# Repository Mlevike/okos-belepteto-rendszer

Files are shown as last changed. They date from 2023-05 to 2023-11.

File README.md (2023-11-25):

# okos-belepteto-rendszer
Okos, internetre kötött beléptető rendszer Raspberry Pi és Arduino alapokon.

# A rendszer leírása
A projekt céja egy hálózaton keresztül elérhető beléptető rendszer megvalósítása, amely engedélyezi a regisztrált felhasználók számára a belépést RFID kártya segítségével. A biztonság növelése érdekében az RFID kártya leovasását követően a felhasználóknak meg kell adni a saját 4 karakter hosszú PIN kódját és/vagy ujjlenyomat segítségével hitelesíteniük kell magukat. A sikeres belépést LED-ekkel, illetve egy 16x2-es karakteres LCD kijelzővel szemléltetjük. 

# Funkciók

- Az RFID jogosultságokat, illetve a felhasználók más releváns adatait egy adatbázisban tároljuk.
- A sikeres belépést az LCD megjelenő felirattal és hangjelzéssel jelezzük.
- Sikertelen belépésről az LCD tájékoztat minket a következő felirattal.
- A sikeres, illetve a sikertelen kilépési kísérletről egy LED, illetve hangjelzés segítségével tájékoztat a rendszer.

# A rendszer tervezett felépítése

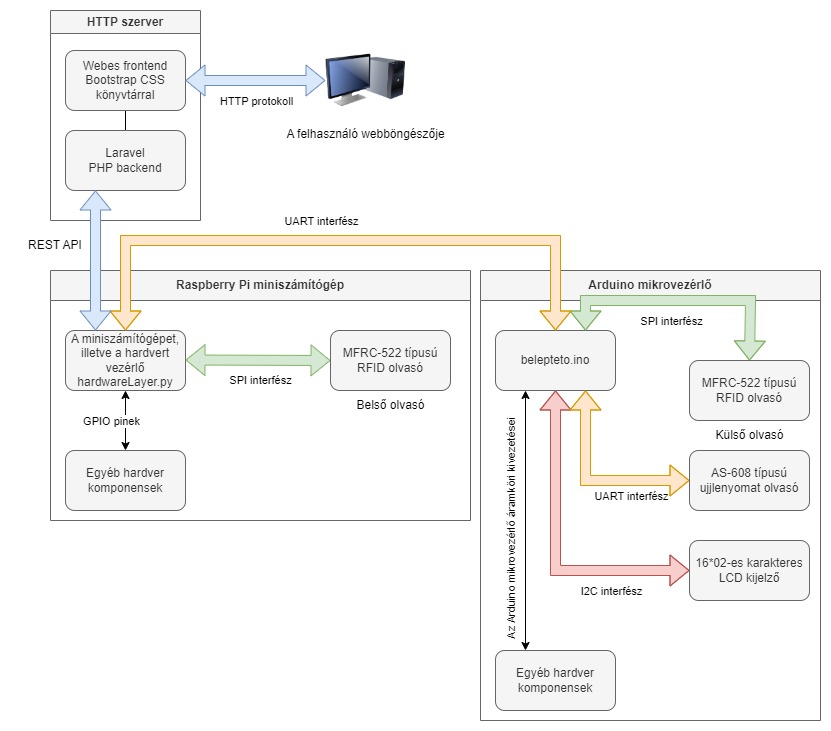
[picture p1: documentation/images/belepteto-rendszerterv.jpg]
Belepteto rendszerterv


# Felhasznált Hardware elemek
- 1 db Raspberry pi 1b rev.2
- 1 db SY-12W-K típusú relé
- 1 db 16x2-es karakteres LCD kijelzővel
- 1 db 4x4-es gomb mátrix
- 2 db RFID olvasó (MFRC-522)
- 1 db Arduino Nano
- 1 db 3,3-5V szintillesztő
- 1 db TM1650 típusú billenytűzet vezérlő IC
- 1 db AS-608 típusú ujjlenyomat olvasó
- 1 db RGB LED
- 2 db Csipogó hangszóró
- Egyéb kisebb alkatrészek

# A rendszer hardveres felépítése
A rendszer két egymástól jól elkülöníthető, ugyanakkor összekapcsolt hardveres részből áll, melyek a következők:

- Az Arduino mikrovezérlőre épülő, melynek felafata a felhasználók beengedéséért felelős külső RFID olvasó, illetve a hozzá tartozó LCD kijelző, ujjlenyomat olvasó, és számbillentyűzet vezérlése.
- A Rasperry Pi, illetve a hozzákapcsolt hardvare elemek, melynek feladata a teljes rendszert vezérlő Python alapú program futtatása, illetve a belső, a felhasználók kiengedéséért felelős RFID kártyaolvasó működtetése.

A kettő rendszer UART soros interfésszel kommunikál egymással, amely megvalósításához szükséges egy 3,3V-5V szintillesztő áramkör.

A két eszköz összekötéséért felelős kábel bekötése:

| A lábel színe és vastagsága | Funkciója | Bekötése az Arduino mikrovezérlőn | Bekötése a Raspberry Pi miniszámítógépen | Megjegyzés |
| --- | --- | --- | --- | --- |
| Vörös / Vastag | 5V táp | VIN (30) | 5V | |
| Fekete / Vastag | Közös föld | GND | GND | |
| Vörös / Vékony | NINCS BEKÖTVE | - | - | |
| Fehér / Vékony | NINCS BEKÖTVE | - | - | |
| Zöld / Vékony | Bejövő UART adatforgalom | TX (1) | RxD / GPIO 16 (10) | A Raspberry Pi felől nézve, 3,3-5V szintillesztőn keresztül a Rasperry Pi védelme érdekében. |
| Sárga / Vékony | Kimenő UART adatforgalom | RX (2) | TxD / GPIO 15 (8) | A Raspberry Pi felől nézve, 3,3-5V szintillesztőn keresztül a Rasperry Pi védelme érdekében. |

## Az Arduino alapú külső olvasó

### Az külső olvasó rövid leírása

A külső olvasó egy Arduino mikrokontroller által vezérelt panel, amelyre csatlakozik a 1602-es LCD kijelző, a kódbillentyűzet, a kártyaolvasó, illetve egy kis hangszóró, amely segítségével a felhasználónak visszajelzést adhatunk a kártya beolvasása során.
A kommunikáció a központi egység és a külső olvasó között soros interfészen valósul meg, az Ardunio, illetve a Raspberry Pi megfelelő lábainak felhasználásával, illetve egy szintillesztő modul közbeikatatásával. A szintillesztő modulra azért van szükség, mert az Arduino a kommunikáció során 5V-os jelszintet használ, míg a Raspberry Pi 3,3V-osat, ezért ha két eszközt közvetlenül csatlakozatnánk, akkor Rasberry Pi károsodna.

### A külső olvasót tartalmazó PCB kivezetései (táblázat)

| Csatlakozás megnevezése | A panel/mikrovezérlő kivezetése | A panelhez csatlakozó modul kivezetése | Megjegyzés |
| --- | --- | --- | --- |
| LCD A kijelző adat kábelei | A4 (23) | SDA | |
| | A5 (24) | SCL | |
| LCD kijelző táp kábelei | 5V | VCC | |
| | GND | GND | |
| MFRC-522 RFID olvasó adat kábelei | D10 (13) | SDA | |
| | D11 (14) | MOSI | |
| | D12 (15) | MISO | |
| | D13 (16) | SCK | |
| MFRC-522 RFID olvasó táp kábelei | 3,3V | 3,3V | |
| | GND | GND | |
| AS-608 ujjlenyomat olvasó adat kábelei | D2 (5) | TX | |
| | D3 (6) | RX | |
| AS-608 ujjlenyomat olvasó táp kábelei  | 3,3V | VCC | |
| | GND | GND | |

### Az olvasó felépítése (Csatlakozók nélkül)

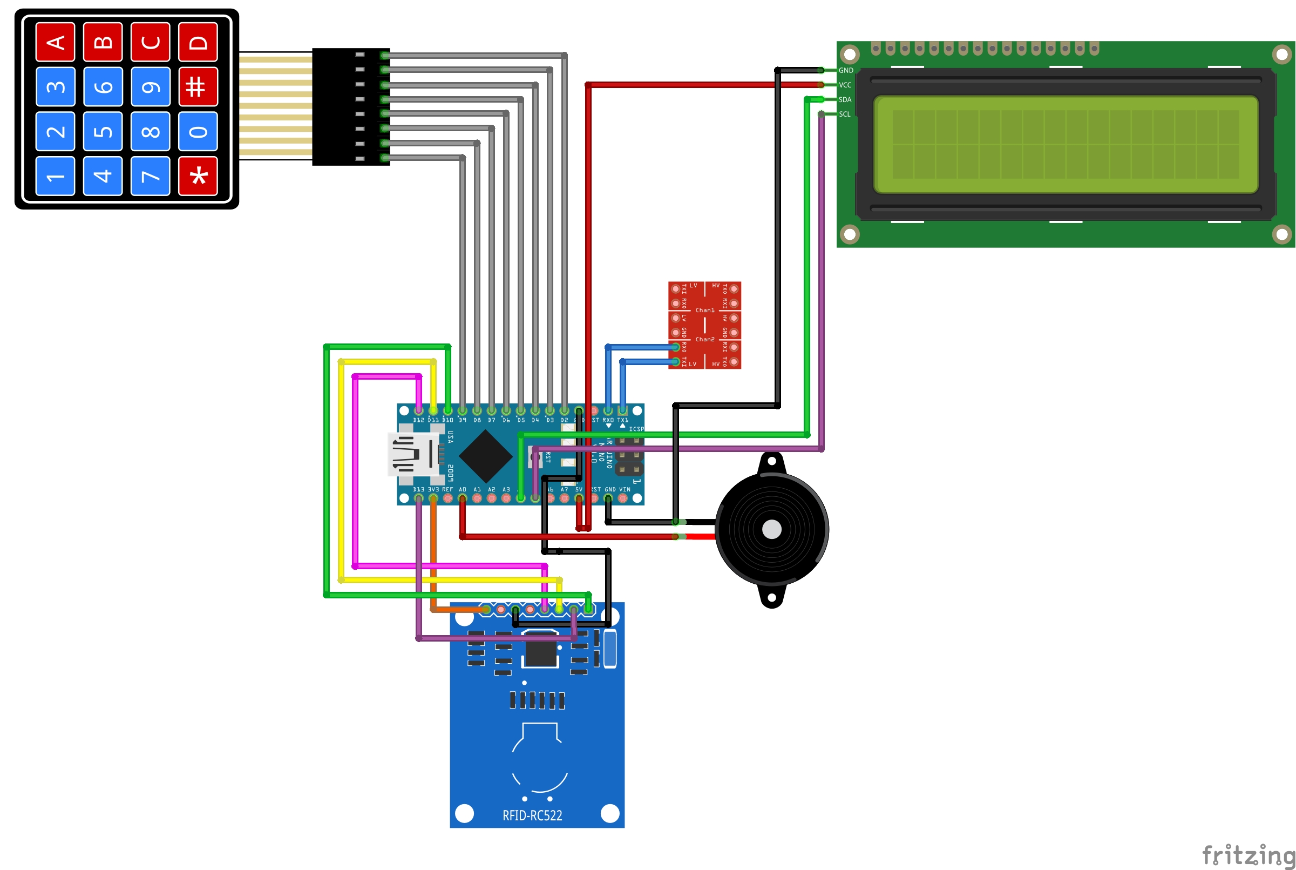
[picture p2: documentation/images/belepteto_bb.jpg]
Beléptető külső olvasó felépítése


### Az olvasó kapcsolási rajza (Csatlakozók nélkül)

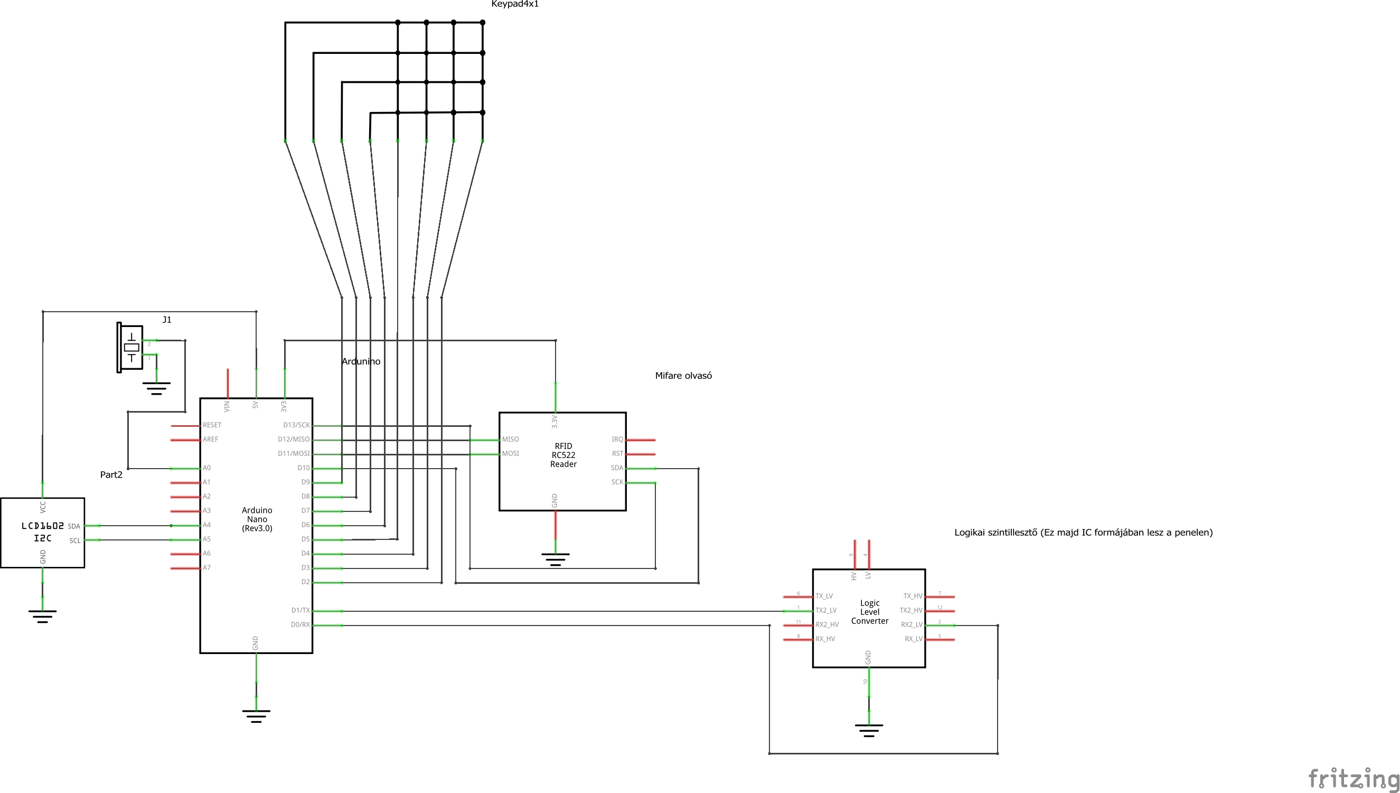
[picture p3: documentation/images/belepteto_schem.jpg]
Beléptető külső olvasó kapcsolási rajza


### Az olvasó nyomtatott áramköri lap terve

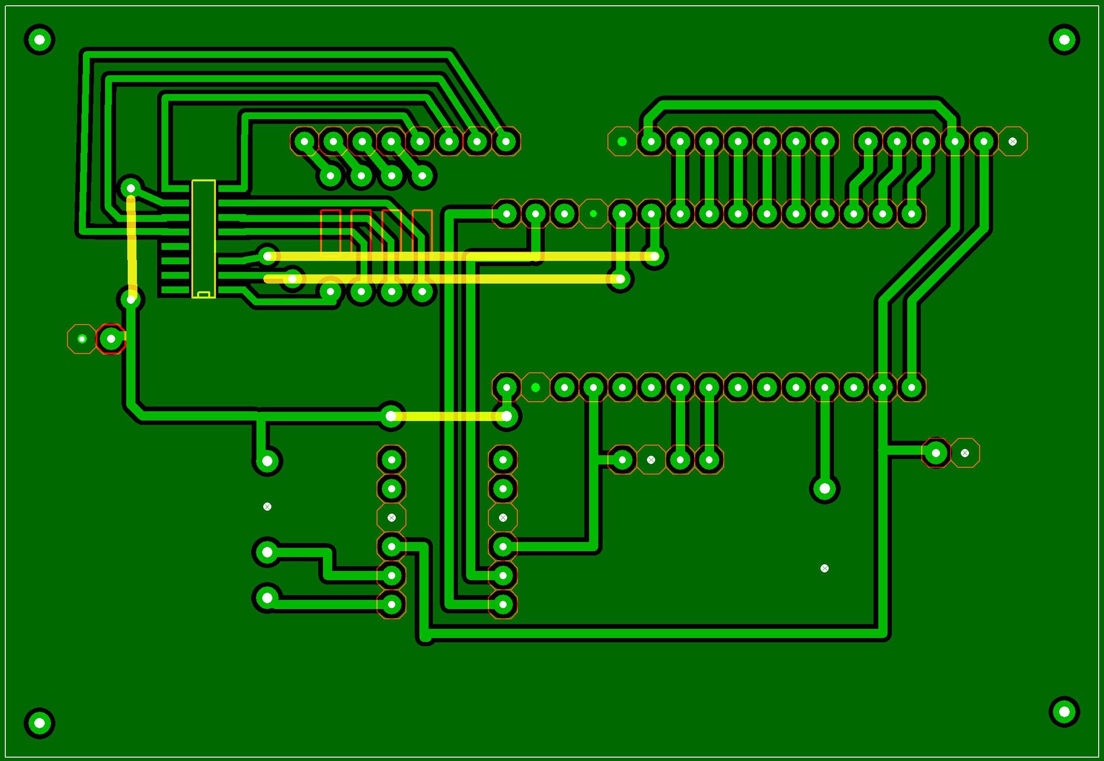
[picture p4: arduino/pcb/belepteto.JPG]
Az olvasó nyomtatott áramköri lap terve


### Az új ujjlenyomat felvételének folyamata

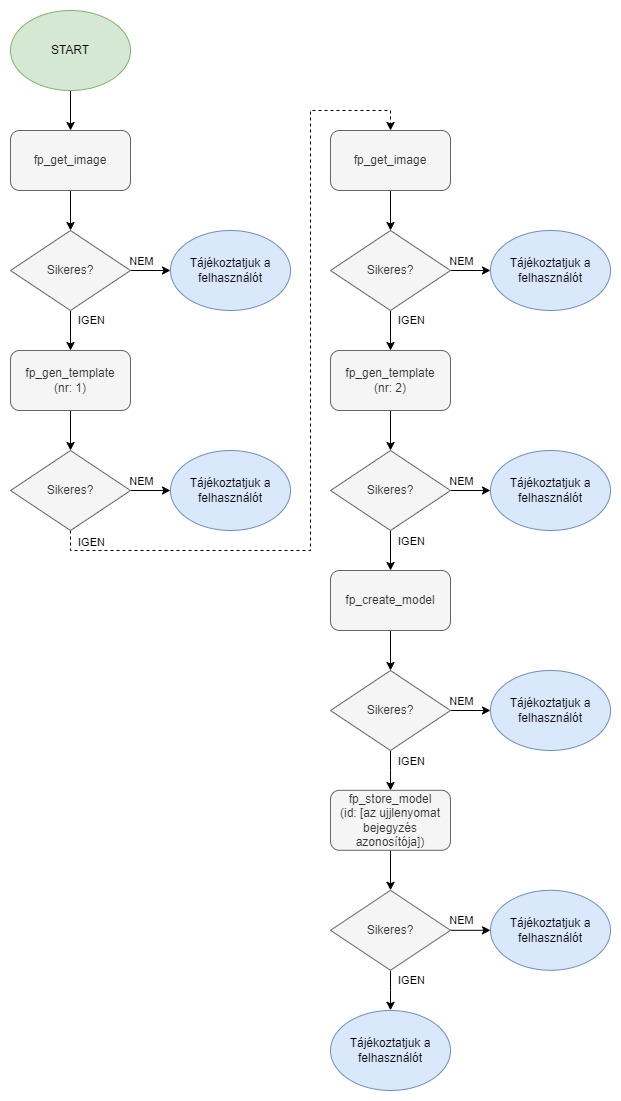
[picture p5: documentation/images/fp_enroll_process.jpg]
Az új ujjlenyomat felvételének folyamata


### Az ujjlenyomat keresésének folyamata

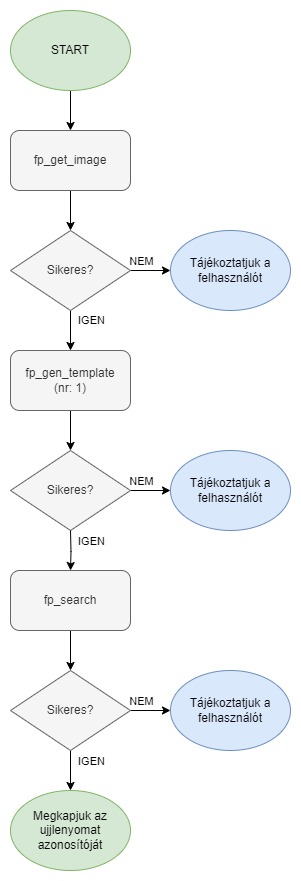
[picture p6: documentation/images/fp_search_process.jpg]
Az ujjlenyomat keresésének folyamata


### A külső olvasó kommunikációja a központi egységgel

A központi egységgel történő kommunikáláshoz [JSON](https://www.w3schools.com/js/js_json_intro.asp) adatszerkezetet használunk, ami így néz ki (ez az adatszerkezet csak minta, a program már nem tartalmazza):

    {
        "key": "show_unknown_card_message"
    }

#### Az adatszerkezetben használt mezők jelentése, rövid leírása:

A jelenlegi adatszerkezetben a "key" nevű mező adja meg a konkrét utasítást, illetve az olvasó felől bejövő adat típusát. A további mezők neve az adott üzenet tartalmától függ.

> **Megjegyzés:** A későbbiekben ez az adatszerkezet a kialakuló igényeknek megfelelően változhat. A változások is majd megtalálhatóak lesznek ebben a dokumentációban.

#### A kommunikáció során használható utasítások, események, a hozzájuk rendelt adatszerkezettel

##### Kártya detektálva üzenet

Ez az üzenet akkor érkezik az olvasó felől, ha egy RFID kártyát hozzá éritettek a leolvasóhoz és az olvasó sikeresen beolvasta a kártya egyedi azonosítóját (UID). Az adatszerkezet a következőképp néz ki:

    {
        "key":"card_detected",
        "uid":"d354ca2e"
    }

##### Kód megadva üzenet

Ez az üzenet akkor érkezik az olvasó felől, ha előzőleg kértük az olvasótól a kód bekérését, és a felhasználó beírta. Az adatszerkezet a következőképp néz ki:

    {
        "key":"code_given",
        "code":[a felhasználó által megadott kód]
    }

##### Az ujjlenyomatolvasással kapcsolatos válasz üzenet

Az ujjlenyomatolvasással kapcsolatos üzenetek válasz üzenete az ujjlenyomat keresés kivételével a következőképp néz ki:

    {
        "key":"fp_done",
        "status": [a művelet sikerességét kifejező numerikus érték]
    }

> **Az ujjlenyomat keresés esetén pedig a "status" helyett "finger" mezőt kapunk, amennyiben a keresés művelet sikeres, akkor megkapjuk az adott ujjlenyomat azonosítóját, egyébként "-1" értéket kapunk vissza.**

##### Kód bekérése

Ha ennek az üzenetnek küldjük az adatszerkezetét az olvasó felé, akkor az bekéri a felhasználótól a kódot, és válaszként visszaküldi egy ["Kód megadva üzenet"](#kód-megadva-esemény) formájában. Az üzenet adatszerkezete a következőképp néz ki:

    {
        "key":"get_code"
    }

##### Tetszőleges szöveg kiírása a kijelzőre

Ha ennek az üzenetnek küldjök az adatszerkezetét az olvasó felé, akkor az LCD kijelzőn tetszőleges feliratokat tudunk megjeleníteni (ékezetes karakterek nélkül!). Az üzenet adatszerkezete a következőképp néz ki:

    {
        "key":"lcd_send_str",
        "str":"[tetszőleges szöveg]"
    }
    
##### Kijelző tartalmának törlése

Ezzel az üzenettel a kijelző tartalmát tudjuk letörölni. Az adatszerkezete a következő:

    {
        "key":"lcd_cls"
    }

##### Tetszőleges helyre ugrás a kurzorral

Ezzel az üzenettel tetszőleges helyre pozicionálhatjuk a kijelző kurzorát. Az adatszerkezete a következő:

    {
        "key":"lcd_goto",
        "row":[sorszám],
        "column":[oszlopszám]
    }

> **Megjegyzés**: Az oszlopszámhoz, illetve a sorszámhoz integer típusú értéket kell írni, különben az üzenet nem fog működni!

##### Software reset végrehajtása

Ha ennek az üzenetnek küldjük az adatszerkezetét az olvasó felé, akkor az Arduino-n szoftveres újraindítást hajtunk végre. Ez a funkció akkor lehet hasznos, ha ha az Arduino valamilyen okból kifolyólag rendellenes tevékenységeket végez. Az üzenet adatszerkezete a következőképp néz ki:

    {
        "key":"sw_rst"
    }
    
##### Képalkotás ujjlenyomatolvasó használatával

Ezen üzenet elküldésével, egy ujjlenyomatképet tudunk rögzíteni.

    {     
        "key": "fp_get_image",
    }

##### Sablon generálás ujjlenyomatolvasó használatával

Ezen üzenet elküldésével, egy ujjlenyomat sablont tudunk generálni.

    {     
        "key": "fp_gen_template",
        "nr": [a sablont tároló buffer azonosítója],
    }

##### Model készítés ujjlenyomatolvasó használatával

Ezen üzenet elküldésével, egy ujjlenyomat modelt tudunk készíteni.

    {     
        "key": "fp_create_model",
    }

##### Model tárolása ujjlenyomatolvasó használatával

Ezen üzenet elküldésével, egy ujjlenyomat modelt tudunk tárolni.

    {     
        "key": "fp_store_model",
        "id": [az ujjlenyomat bejegyzés azonosítója],
    }

##### Ujjlenyomat azonosító keresése az ujjlenyomat olvasó használatával

Ezen üzenet elküldésével, egy ujjlenyomat modelt tudunk tárolni.

    {     
        "key": "fp_search",
    }

## A Raspberry Pi alapú belső olvasó

A Raspberry Pi alapú belső olvasó egy Raspbery Pi 1 rev.2 miniszámítógépen alapul, mely futtat egy Python 3 nyelven írt programot, ami a felhasználók PHP backendenden történő hitelesítéséért felel. Ez a program vezérli a külső olvasót is JSON adatszerkezetek segítségével.

### A belső olvasót tartalmazó PCB kivezetései (táblázat)

| Csatlakozás megnevezése | A panel/miniszámítógép kivezetése | A panelhez csatlakozó modul kivezetése | Megjegyzés |
| --- | --- | --- | --- |
| MFRC-522 RFID olvasó adat kábelei | MOSI/GPIO10 (19) | MOSI | |
| | MISO/GPIO9 (21) | MISO | |
| | SCLK/GPIO11 (23) | SCK | |
| | CE0/GPIO8 (24) | SDA | |
| MFRC-522 RFID olvasó táp kábelei | 3,3V | 3,3V | |
| | GND | GND | |

### Az olvasó kapcsolási rajza (Csatlakozók nélkül)

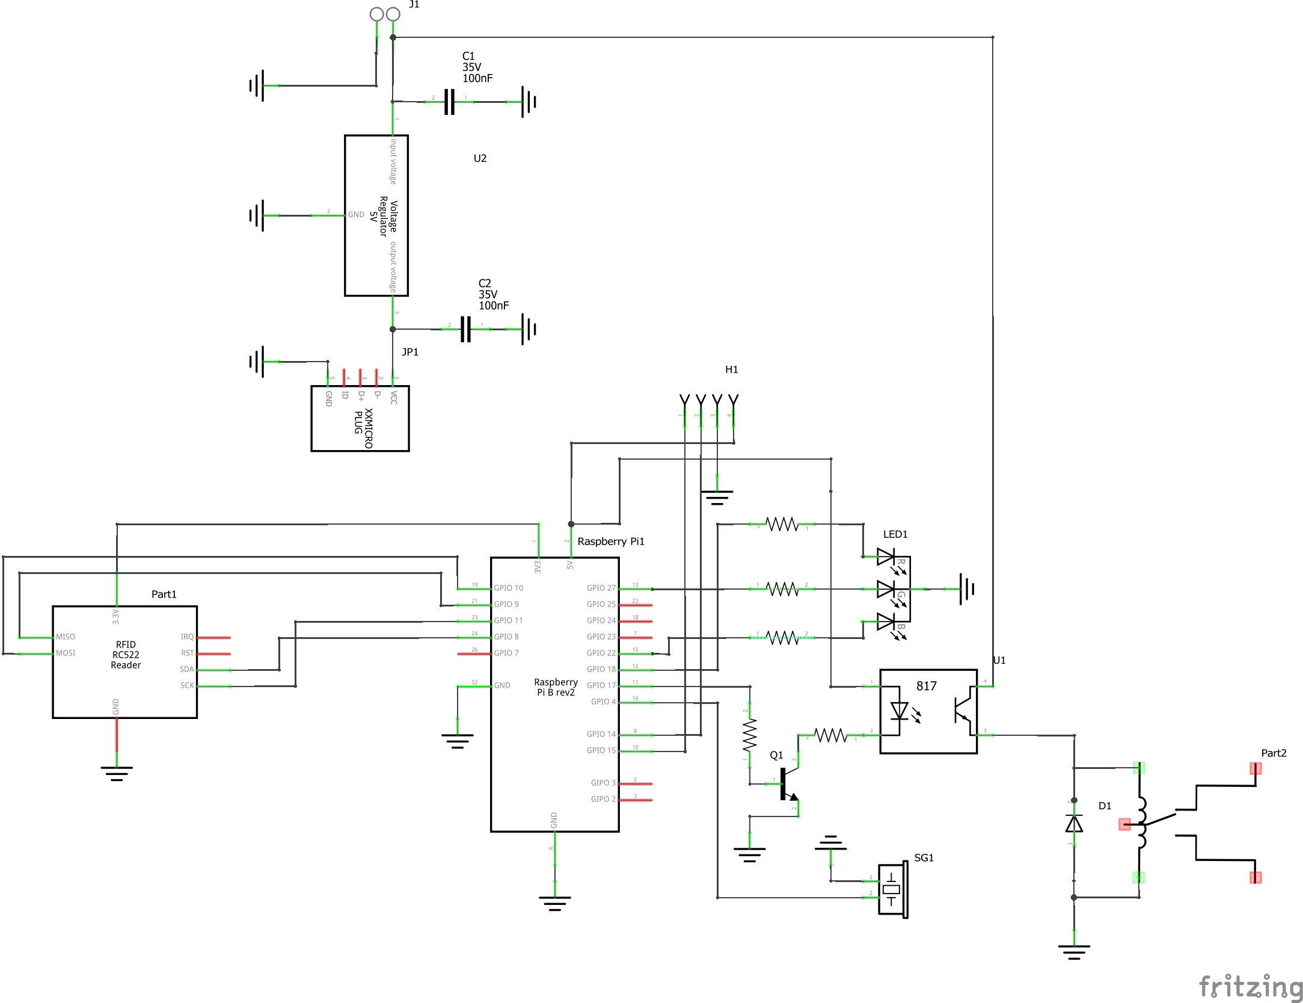
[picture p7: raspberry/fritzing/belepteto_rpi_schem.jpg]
Beléptető belső olvasó kapcsolási rajza


### Az olvasó nyomtatott áramköri terve

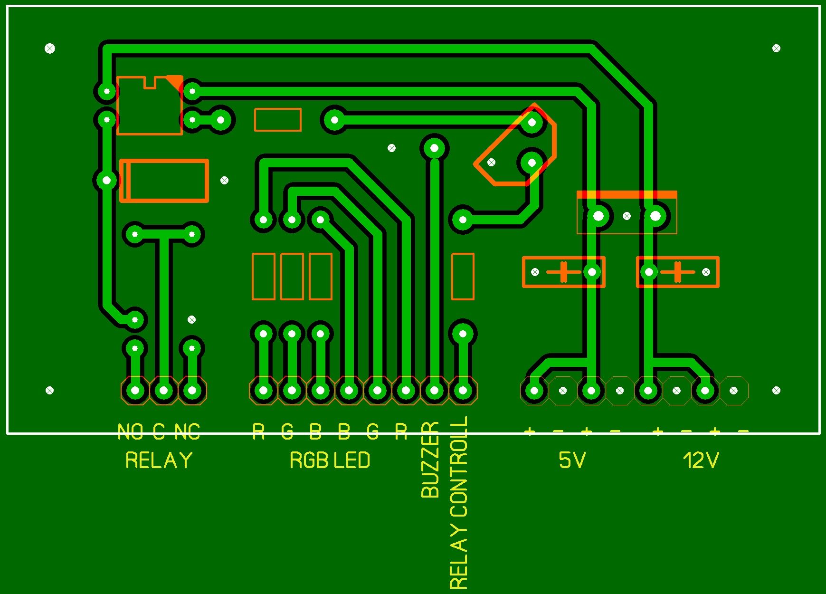
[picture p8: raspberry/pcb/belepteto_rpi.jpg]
Beléptető belső olvasó nyomtatott áramköri terve


# A rendszer szoftveres felépítése

A rendszer szoftveresen a következő három részből áll:
 - Laravel PHP keretrendszer alapú webalkalmazás: Ez a web alkalmazás felelős a felhasználók hitelesítéséért, illetve a webes adminfelületért.
 - A belső olvasón futtatandó Python nyelvű program: Ez felelős a felhasználók hitelesítéssért, illetve az RFID olvasók vezérlésséért.
- Az Arduino Mikrokontrolleren futtatot kód: Ezt a programot vezérli a Python kód és ezáltal a mikrovezérlőre kapcsolt LCD kijelzőt, kódbillentyűzetet és RFID olvasót éri el.

## A Laravel PHP keretrendszer alapú webalkalmazás

### A projekt adatbázis modelljének felépítése
#### History model

A History model a következő attribútumokat tartalmazza:
- arriveTime: A felhasználó beléptetőrenszeren keresztüli objektumba való belépésének időpontja.
- successful: A felhasználó objektumba történő belépésének sikersségét rögzítő attribútum.
- leaveTime: A felhasználó beléptetőrenszeren keresztüli objektumból való kilépésének időpontja.
- workTime: A felhasználó objetumban töltött ideje, az arriveTime és leaveTime különbsége.
- direction: A ki/be léptetés iránya.
- userId: Az érintett felhasználó azonosítója.
- cardId: A belépéshez használt kártya azonosítója.

#### User model

A User model a következő attribútumokat tartalmazza:
- name: Az érintett felhasználó neve.
- picture: Az érintett felhasználó profilképe.
- code: Az érintett felhsználó belépési kódja.
- fingerprint: Az érintett felhasználó ujjlenyomata.
- language: Az érintett felhasználó nyelvi beállítása.
- profile: Az adott felhasználó profilja.
- role: Az adott felhasználó jogosultásgi szintje, szerepköre.
- isEntryEnabled: Az adott felhasználó rendelkezik-e az objektumba történő belépés jogosultsággával?
- email: Az érintett felhasználó email címe.
- password: Az érintett felhasználó jelszava titkosítva.
- remember_token: A felhasználó megjegyzéséért felelős token a Laravel keretrendszerben.
- cardId: Az érintett felhasználó beléppését biztosító kártya azonosítója.
- isHere: A felhasználó ittlétét tároló attribútum.
- email_verified_at: Az email cím visszaigazolásának időpontja.

#### Settings model

A Settings model a következő attribútumokat tartalmazza:
- setting_name: A beállítás neve.
- setting_value: A beállítás értéke.

### A projektben használt útvonalak
- `/`: Az oldal kiindulópontja, a dashboard.blade.php nézetet hívja meg. (Ideiglenesen át van írányítva a /users-re)
- `/logs`: Az oldalon, illetve a beléptetés során történő esetleges események visszanézhetőségét biztosító oldal, a logs.blade.php nézetet hívja meg.
- `/users`: Az oldal felhasználó kezezelését biztosító oldala, az UsersViewController index() metódusát hívja meg.
- `/users/add`: Az oldal felhasználók hozzáadását biztosító oldala, az UsersViewController add() metódusát hívja meg.
- `/users/edit/{userId}`: Az oldal felhasználók módosítását biztosító oldala, az UsersViewController edit() metódusát hívja meg.
- `/users/delete/{userId}`: Az oldal felhasználók hozzáadását biztosító oldala, az UsersViewController delete() metódusát hívja meg.
- `/current`: A legutóbbi belépési kísérletet mutató nézet elérési útja.
- `/api/validation/validate`: Az authentikációra szolgáló útvonal, a ValidationController validate() metódusát hívja meg.
- `/api/validation/get-methods`: Az authentikációs metódusokat lekérdezó útvonal, a ValidationController getMethods() metódusát hívja meg.
- `/log`: Egy adott belépési kísérlet sikerességének mentésére szolgló útvonal.
- `/setup`: Majd az eszköz beállításra fog szolgálni, de még fejlesztés alatt..

### A projektben használt Laravel Controllerek
- DashboardController: A vezérlőpulttal kapcsolatos műveletek elvégzéséért felelős vezérlő.
- LogController: A logok oldal adatainak összegyűjtéséért felelős vezérlő.
- SystemController: A beléptetőrendszer Raspberry Pi miniszámítógépén futó programnak parancsokat átadó vezérlő.
- UsersViewController: A felhasználókkal kapcsolatos műveletekért felelős vezérlő.
- ValidationController: Az authentikációért felelős vezérlő.

### A projektben található artisan parancsok
A projekt tartalmaz pár olyan parancsot, melyeket a konzolról tudunk elindítani és valamilyen hatással vannak a Laravel backend működésére. Ezek a következők:
- CheckOperationTimeout: A rendszernek átadott parancsok időbeli érvényességét ellenőrnző parancs, a helyes működéséhez bizonyos időközönként automatizáltan kell elindítani. Az automatizált elindításhoz egy jó eszköz a Linux alapú operációs rendszerekben alapból megtalálható cron időzítő.
- GenerateDefaultSetting: A rendszer működéséhez nélkülözhetetlen, az adatbázisban tárolt változókat definiálja az a parancs. Ilyen változó páldául az access_token is.
- CreateFirstUser: A rendszer telepítése során az első, admin jogosultággal rendelkező felhasználó létrehozására lehet használni.

### A web backend telepítése Docker segítségével

0. Telepítsd a Docker Desktop alkalmazást, amennyiben nem található meg a számítógépeden, az alkalmazás innen tölthető le [https://www.docker.com/products/docker-desktop/](https://www.docker.com/products/docker-desktop/)

1. Indítsd el a Docker Desktop alkalmazást amennyiben nem futna.

2. Lépj a projekt `/backend/.docker` mappájába!

3. A megfelelő docker konténerek telepítéséhez add ki a következő parancsot:
```
docker-compose up
```
4. A `/backend` mappában a Docker Desktop segítségével futtasd a következő parancsot az adatbázis migrációk alkalmazásához:
```
php artisan migrate
```
5. Hozzuk létre a kezdeti beállításokat a következő paranccsal:
```
php artisan app:generate-default-settings
```
6. Hozzuk létre a kezdeti felhasználót a következő paranccsal:
```
php artisan app:create-first-user
```
**Megjegyzés:** Amennyiben paraméterként mást nem adunk meg, úgy az alapértelmezett belépési adatok a következők lesznek:
  - email: admin@admin.com
  - jelszó: jelszo

**Megjegyzés:** Amennyiben a helyi, fejlesztői gépen futtatod a Laravel keretrendszert, abban az esetben a sikeres telepítést követően a következő címen lesz elérhető az oldal: `127.0.0.1:8000`.

# Felhasznált software eszközök

## A projekt során használt Laravel modulok
- laravel/fortify a felhasználók webes felületen történő hitelesítéséhez.
- yoeriboven/laravel-log-db az adatbázisban történő logoláshoz.

## A projekt frontendjének kialakítására használt külső könyvtárak
- https://github.com/lipis/flag-icons
- Bootstrap
- Bootstrap icons

## Az Arduino programhoz felhasznált külső könyvtárak:

- HD44780_LCD_PCF8574 i2c LCD controller library - https://github.com/gavinlyonsrepo/HD44780_LCD_PCF8574
- MFRC522v2 library - https://github.com/OSSLibraries/Arduino_MFRC522v2
- ArdunioJSON - https://arduinojson.org/
- Adafruit fingerprint libary - https://github.com/adafruit/Adafruit-Fingerprint-Sensor-Library/
- TM16xx libary - https://github.com/maxint-rd/TM16xx/

## A Rasperry Pi programhoz használt, az eszköz operációs rendszerére feltelepítendő szoftverek:
- fswebcam, szoftver az USB-s kamera eléréséhez - http://www.sanslogic.co.uk/fswebcam/
- - phpmyadmin

## A Rasperry Pi programhoz a Python PIP csomagkezelő szoftver által feltelpített könyvtárak:
- pip
- gpio
- pyserial

  ## A dokumentáció írása során felhasznált források
- [https://hub.docker.com/r/bitnami/laravel](https://hub.docker.com/r/bitnami/laravel)

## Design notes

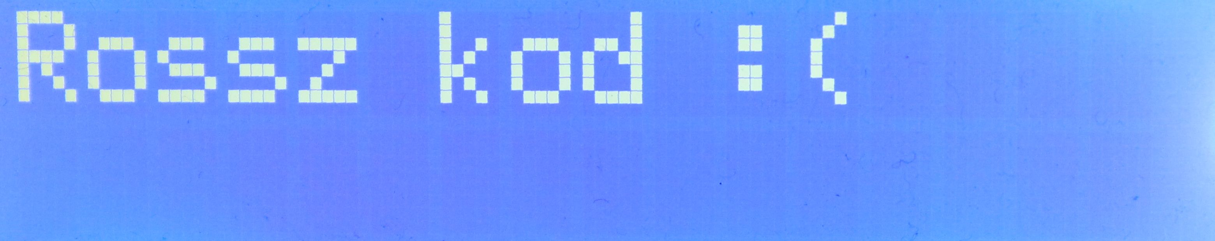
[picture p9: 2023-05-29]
documentation/images/belepteto_show_wrong_code_message.jpg

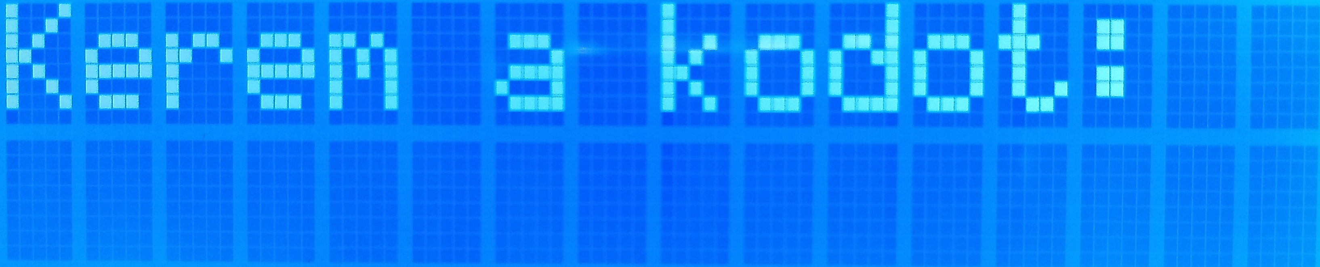
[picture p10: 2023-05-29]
documentation/images/belepteto_get_code.jpg

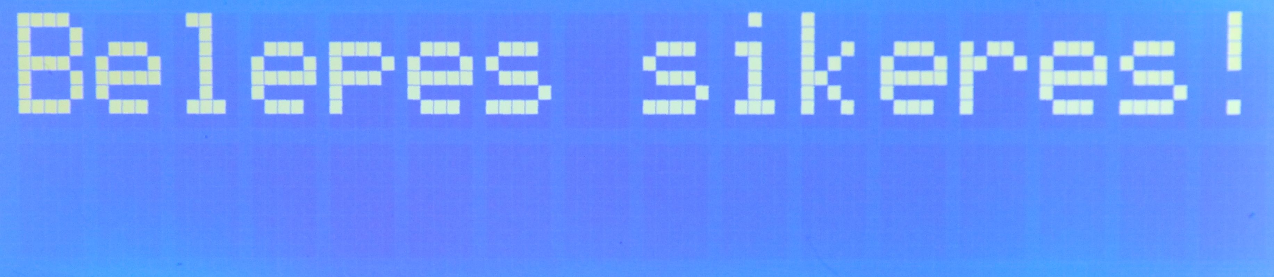
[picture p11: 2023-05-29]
documentation/images/belepteto_show_success_message.jpg

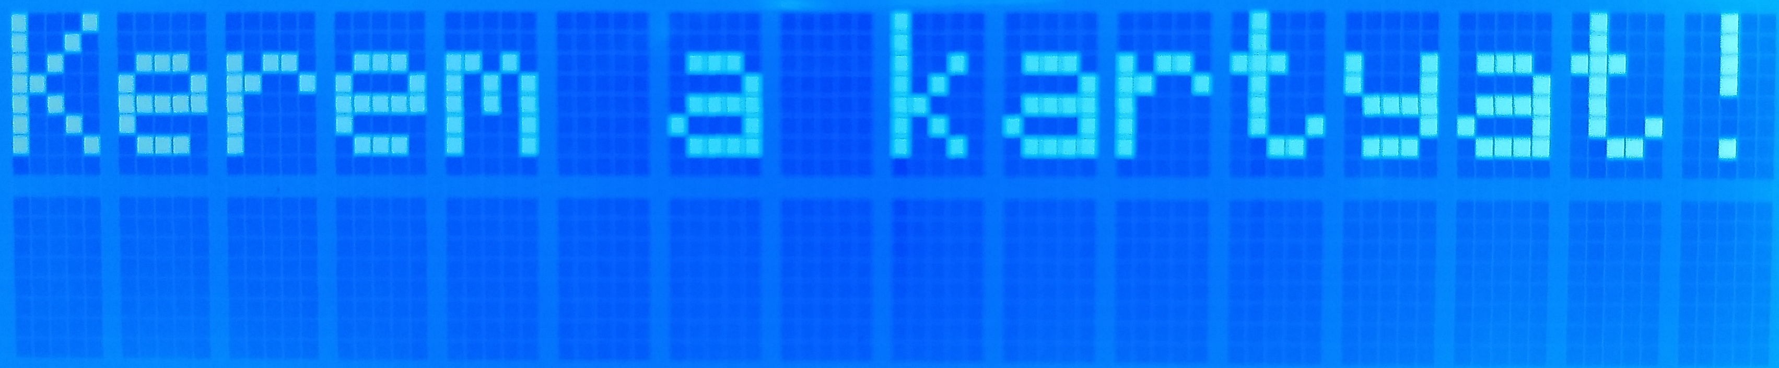
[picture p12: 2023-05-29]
documentation/images/belepteto_show_get_card_message.jpg

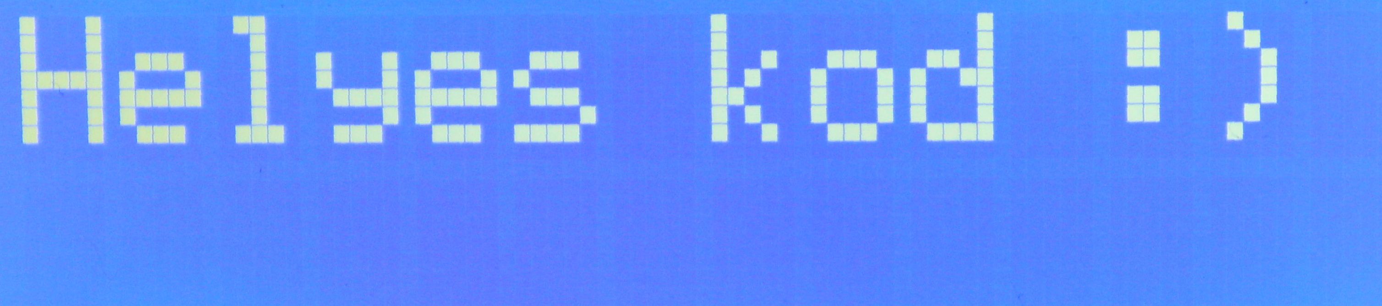
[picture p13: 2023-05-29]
documentation/images/belepteto_show_good_code_message.jpg

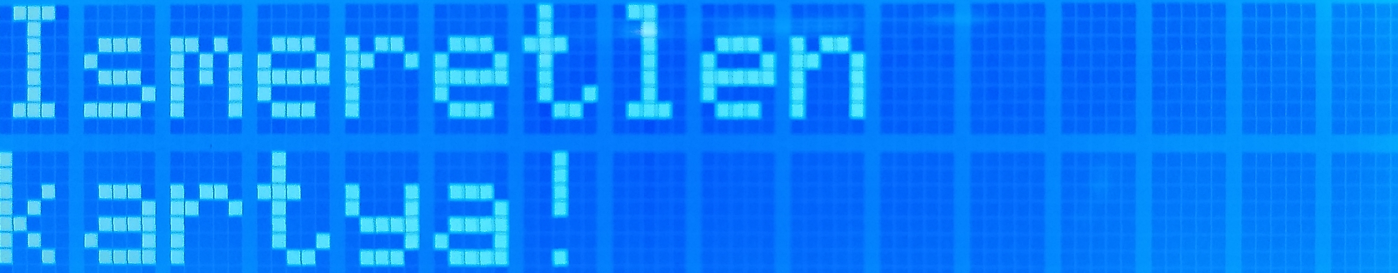
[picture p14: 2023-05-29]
documentation/images/belepteto_show_unknown_card_message.jpg

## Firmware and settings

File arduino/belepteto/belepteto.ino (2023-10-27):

//Beimportáljuk a szükséges külső könyvtárakat
#include <ArduinoJson.h>
#include "HD44780_LCD_PCF8574.h"
#include <MFRC522v2.h>
#include <MFRC522DriverSPI.h>
#include <MFRC522DriverPinSimple.h>
#include <MFRC522Debug.h>
#include <Adafruit_Fingerprint.h> 
#include <TM1650.h>

//Definiáljuk a beállításokat

#define BUZZER_FREQUENCY 2400 //Megadjuk a frekvenciát Hz-ben
#define BUZZER_PIN A0 //Megadjuk a kimeneti pin-t
#define SHORT_TIME 500 //Megadjuk a rövid csippanás idejét (ms)
#define LONG_TIME 1000 //Megadjuk a hosszú csippanás idejét (ms)
#define MUTED true //Megadjuk, hogy le van-e némítva az eszköz?

#define MFRC522_SS_PIN 10 //Megadjuk a SPI SS lábának számát

#define FPR_SOFT_SERIAL_RX_PIN 2 //Megadjuk a softwareSerial RX lábának számát
#define FPR_SOFT_SERIAL_TX_PIN 3 //Megadjuk a softwareSerial TX lábának számát
#define FPR_SERIAL_BAUDRATE 115200 //Megadjuk a softwareSerial sebességét

#define TM1650_SDA_PIN 8 //Megadjuk a TM1650-es billenytű vezérlő IC felé vezető SDA lábnak számát
#define TM1650_SCL_PIN 9 //Megadjuk a TM1650-es billenytű vezérlő IC felé vezető SCL lábnak számát

#define LCD_ROW_NUMBER 2 //Megadjuk, hogy hány sor magas az LCD kijelzőnk
#define LCD_COLUMN_NUMBER 16 //Megadjuk, hogy hány oszlop széles az LCD kijelzőnk
#define LCD_ADDRESS 0x27 //Megadjuk az LCD kijelző címét
#define LCD_BACKLIGHT true //Megadjuk, hogy az inicializációkor bekapcsoljuk-e az LCD kijelző háttérvilágítását

#define STATIC_JSON_DOCUMENT_SIZE 200 //Megadjuk, hogy a JSON feldolgozó mekkora méretű területet foglalahat a memóriában (byte)
#define SERIAL_BAUDRATE 9600 //Megadjuk a soros kommunikáció sebességét

MFRC522DriverPinSimple ss_pin(MFRC522_SS_PIN); //Definiáljuk a SPI SS lábát
MFRC522DriverSPI driver{ss_pin}; //Inicializáljuk az SPI meghajtót

SoftwareSerial mySerial(FPR_SOFT_SERIAL_RX_PIN, FPR_SOFT_SERIAL_TX_PIN); //Inicializáljuk a szoftveres soros portot
Adafruit_Fingerprint finger = Adafruit_Fingerprint(&mySerial); //Inicializáljuk az ujjlenyomat olvasó könyvtárat

TM1650 module(TM1650_SDA_PIN, TM1650_SCL_PIN); //Inicializáljuk a keypad vezérlő modult, SDA=8; SCL=9

HD44780LCD myLCD(LCD_ROW_NUMBER, LCD_COLUMN_NUMBER, LCD_ADDRESS, &Wire); //Iniciálizáljuk az LCD kijelzőt
MFRC522 mfrc522{driver};  //Inicializáljuk az RFID olvasót
StaticJsonDocument<STATIC_JSON_DOCUMENT_SIZE> rx; //Definiáljuk a bemenő JSON adatszerkezetet
StaticJsonDocument<STATIC_JSON_DOCUMENT_SIZE> tx; //Definiáljuk a kimenő JSON adatszerkezetet

char TranslateKey(uint32_t keyValue){ //Billentyűkódból karakterre fordító metódus
  //Definiáljuk a billentyűzet kiosztását
  typedef struct key{
  uint32_t keyCode;
  char key;
  };

  /*key keys[1] = { //A billentyűk elrendezése
  {2, '1'}};*/
  
  key keys[10] = { //A billentyűk elrendezése
  {2, '1'}, {32, '2'}, {512, '3'}, 
  {4, '4'}, {64, '5'}, {1024, '6'}, 
  {8, '7'}, {128, '8'}, {2048, '9'}, 
  {16, '0'},
  };


  for(int i = 0; i < 10; i++){ //Társítsuk a kapott kódot a n
    if(keys[i].keyCode == keyValue){
      return keys[i].key;
    }
  }
  return ' '; //Amennyiben nem valós billenytűre hivatkoztunk, akkor addjunk ' ' karaktert
}

String GetCode(char mask){  //Kód kérő függvény
  String code = ""; //Létrehozunk egy sztringet a kód tárolására
  for(int i = 0; i < 4; i++){ //Azért hívjuk meg négyszer a karakterbekérő függvényt, mert négy számjegyből áll a kód
    char sample1 = ' '; //Létrehozunk egy változót az első mintavételnek
    char sample2 = ' '; //Létrehozunk egy változót az második mintavételnek
    while(!isDigit(sample1)){ 
      while((sample1 != sample2) || sample1 == ' '){ //Addig olvasunk be a billentyűzetről, amíg a két minta nem egyezik meg
        sample1 = TranslateKey(module.getButtons()); //Lekérdezzük a billenytűzet kezelő modultól a gombok állapotát
        delay(20); //Várunk egy picit a prell kivédése érdekében
        sample2 = TranslateKey(module.getButtons()); //Lekérdezzük a billenytűzet kezelő modultól a gombok állapotát
      }
      while(sample1 == sample2){ //Várunk arra, hogy a felhasználó felengedje a gombot
        sample2 = TranslateKey(module.getButtons());
      }; 
    }
    code = code + sample1; //A key változó tartalmát hozzáfűzzük a code változóhoz
    myLCD.PCF8574_LCDSendChar(mask); //Kiíratjuk a *-ot az LCD kijelzőre
  }
  return(code); //Visszaadjuk a kódot sztringként*/
}


void LcdClearScreen(){ //Az LCD tartaémának törléséért felelős metódus
  myLCD.PCF8574_LCDClearScreen(); //LCD letörlése
}

void ShortBeep(){ //A rövid csippanásért felelős metódus
  if(!MUTED){ //Akkor működjön csak, ha a MUTED értéke false
  pinMode(BUZZER_PIN, OUTPUT); //Kimeneti pin beálltása
  tone(BUZZER_PIN, BUZZER_FREQUENCY); //Hang generálása
  delay(SHORT_TIME); //Várakozás SHORT_TIME időtartamnyit
  noTone(BUZZER_PIN); //Hang generálásának befejezése
  }
}

void LcdGoto(int row, int column){ //Az LCD-n adott pozicióra ugrásért felelő metódus
  if(row == 0){
    myLCD.PCF8574_LCDGOTO(myLCD.LCDLineNumberOne, column); //Pozicióra ugrás, ha row == 0
  }
  if(row == 1){
    myLCD.PCF8574_LCDGOTO(myLCD.LCDLineNumberTwo, column); //Pozicióra ugrás, ha row == 1
  }
           
}

void LcdSendString(String text){ //Az string LCD-re történő kiíratásáért felelő metódus
  char charBuf[text.length() + 1]; //Buffer létrehozása a String --> char[] konvertáláshoz
  text.toCharArray(charBuf, text.length() + 1); //String átkonvertálása char[]-é
  myLCD.PCF8574_LCDSendString(charBuf); //Kiirjuk az üzenetet az LCD-re
}

void SoftwareReset(){ //Az eszköz szoftverből való újraindítására szolgáló metódus
  asm volatile ("jmp 0"); //Assembly jmp 0 parancs 
}

int FingerprintGetImage(){ //Az ujjlenyomatolvasó általi lépkészítésért felelős metódus
  int p = -1; //Ennek a változónak az értéket adjuk vissza, hiba esetén marad -1
   while (p != FINGERPRINT_OK) { //Megróbálkozunk az ujjlenyomat felvétellel
    p = finger.getImage(); //Itt nincs hibakijelzés
   }
   return p;
}

int FingerprintGenerateTemplate(int nr){ //Az ujjenyomat olvasó általi sablongenerálásért felelős metódus
  return finger.image2Tz(nr); //Az ujjlenyomat olvasó által visszaadott értéket adjuk vissza
}

int FingerprintCreateModel(){ //Az ujjenyomat olvasó általi modelkészítésért felelős metódus
  return finger.createModel(); //Az ujjlenyomat olvasó által visszaadott értéket adjuk vissza
}

int FingerprintStoreModel(int id){ //Az ujjenyomat olvasó általi tárolásért felelős metódus
  return finger.storeModel(id); //Az ujjlenyomat olvasó által visszaadott értéket adjuk vissza
}

int FingerprintSearch(){ //Az ujjlenyomat alapján történő azonosító keresésért felelős metódus. Ez nem az állapotot adja vissza, hanem az azonosítót.
  int p = finger.fingerSearch();
  if (p == FINGERPRINT_OK) { //Hiba esetén -1-et adunk vissza
    return finger.fingerID;
  }else{
    return -1;  
  }
}

void setup(){
  bool fingerprintOK = false; //Létrehozunk egy változót az ujjlenyomat olvasó állapotának reprezentálásához, memóriatakaréskosság végett egyenlőre ide rakjuk
  ShortBeep(); //Csak teszteléshez
  delay(50);
  //Beállítjuk az LCD kijelzőt
  myLCD.PCF8574_LCDBackLightSet(LCD_BACKLIGHT); //Engedélyezzük az LCD háttérvilágítását
  myLCD.PCF8574_LCDInit(myLCD.LCDCursorTypeOff); //Ne jelenítsük meg a kurzort az LCD kijelzőn
  Serial.begin(SERIAL_BAUDRATE); //Elindítjuk a soros kommunikációt
  mfrc522.PCD_Init();  //Inicializáljuk az RFID olvasót
  finger.begin(FPR_SERIAL_BAUDRATE); //Beállítjuk az ujjlenyomat olvasó kapcsolatának sebességét
  if (finger.verifyPassword()) {
    fingerprintOK = true;
  }
}


void loop(){
  //Figyeljük a bejövő soros adatforgalmat
  if (Serial.available()){
    deserializeJson(rx, Serial);
      if(rx["key"] == "get_code"){
        //Elküldjük válaszként a kódot!
        tx["key"] = "code_given";
        tx["code"] = GetCode('*'); 
        serializeJson(tx, Serial); //Szerializáljuk és továbbítjuk soros kommunikáción keresztül a JSON adatszerkezetünket
        Serial.println(); //Küldjünk egy sor végét is a soros kommunikáción keresztül
        tx.clear(); //Töröljük a json adatszerkezet tartalmát, mert már nincs szükségünk rá!
      }
      if(rx["key"] == "fp_get_image"){
        int p = FingerprintGetImage();
        tx["key"] = "fp_done"; //Megadjuk az eseményt (card_detected)
        tx["status"] = p; //Hozzáadjuk az adatszerkezethez az uid-t
        serializeJson(tx, Serial); //Szerializáljuk és továbbítjuk soros kommunikáción keresztül a JSON adatszerkezetünket
        Serial.println(); //Küldjünk egy sor végét is a soros kommunikáción keresztül
        tx.clear(); //Töröljük a json adatszerkezet tartalmát, mert már nincs szükségünk rá!
      }

      if(rx["key"] == "fp_gen_template"){
        int p = FingerprintGenerateTemplate(rx["nr"]);
        tx["key"] = "fp_done"; //Megadjuk az eseményt (card_detected)
        tx["status"] = p; //Hozzáadjuk az adatszerkezethez az uid-t
        serializeJson(tx, Serial); //Szerializáljuk és továbbítjuk soros kommunikáción keresztül a JSON adatszerkezetünket
        Serial.println(); //Küldjünk egy sor végét is a soros kommunikáción keresztül
        tx.clear(); //Töröljük a json adatszerkezet tartalmát, mert már nincs szükségünk rá!
      }
      
      if(rx["key"] == "fp_create_model"){
        int p = FingerprintCreateModel();
        tx["key"] = "fp_done"; //Megadjuk az eseményt (card_detected)
        tx["status"] = p; //Hozzáadjuk az adatszerkezethez az uid-t
        serializeJson(tx, Serial); //Szerializáljuk és továbbítjuk soros kommunikáción keresztül a JSON adatszerkezetünket
        Serial.println(); //Küldjünk egy sor végét is a soros kommunikáción keresztül
        tx.clear(); //Töröljük a json adatszerkezet tartalmát, mert már nincs szükségünk rá!
      }

      if(rx["key"] == "fp_store_model"){
        int p = FingerprintStoreModel(rx["id"]);
        tx["key"] = "fp_done"; //Megadjuk az eseményt (card_detected)
        tx["status"] = p; //Hozzáadjuk az adatszerkezethez az uid-t
        serializeJson(tx, Serial); //Szerializáljuk és továbbítjuk soros kommunikáción keresztül a JSON adatszerkezetünket
        Serial.println(); //Küldjünk egy sor végét is a soros kommunikáción keresztül
        tx.clear(); //Töröljük a json adatszerkezet tartalmát, mert már nincs szükségünk rá!
      }

      if(rx["key"] == "fp_search"){
        int p = {FingerprintSearch()};
        tx["key"] = "fp_done"; //Megadjuk az eseményt
        tx["finger"] = p; 
        serializeJson(tx, Serial); //Szerializáljuk és továbbítjuk soros kommunikáción keresztül a JSON adatszerkezetünket
        Serial.println(); //Küldjünk egy sor végét is a soros kommunikáción keresztül
        tx.clear(); //Töröljük a json adatszerkezet tartalmát, mert már nincs szükségünk rá!
      }

      if(rx["key"] == "lcd_goto"){
        LcdGoto(rx["row"], rx["column"]);
      }

      if(rx["key"] == "get_status"){
        tx["key"] = "status"; //Megadjuk az eseményt
        tx["status"] = 0; 
        serializeJson(tx, Serial); //Szerializáljuk és továbbítjuk soros kommunikáción keresztül a JSON adatszerkezetünket
        Serial.println(); //Küldjünk egy sor végét is a soros kommunikáción keresztül
        tx.clear(); //Töröljük a json adatszerkezet tartalmát, mert már nincs szükségünk rá!
      }

      if(rx["key"] == "lcd_cls"){
        LcdClearScreen();
      }
      
      if(rx["key"] == "lcd_send_str"){
        LcdSendString(rx["str"]);
      }
      if(rx["key"] == "sw_rst"){
        SoftwareReset();
      }
    
    rx.clear(); //Töröljük a json adatszerkezet tartalmát, mert már nincs szükségünk rá!  
  }
  //Figyeljük, hogy érintenek-e az olvasóhoz új kártyát
  if (!mfrc522.PICC_IsNewCardPresent()) {
    return;
  }
  if (!mfrc522.PICC_ReadCardSerial()) {
    return;
  }
  //Beolvassuk a kártya egyedi gyártó által beleégetett azonosítóját (UID)
  ShortBeep(); //Csak teszteléshez
  String cardUID = "";
  for (int i = 0; i < mfrc522.uid.size; i++) {
    cardUID += String(mfrc522.uid.uidByte[i], HEX);
  }
  mfrc522.PICC_HaltA(); //Befelyzzük a kártya olvasá
  tx["key"] = "card_detected"; //Megadjuk az eseményt (card_detected)
  tx["uid"] = cardUID; //Hozzáadjuk az adatszerkezethez az uid-t
  serializeJson(tx, Serial); //Szerializáljuk és továbbítjuk soros kommunikáción keresztül a JSON adatszerkezetünket
  Serial.println(); //Küldjünk egy sor végét is a soros kommunikáción keresztül
  tx.clear(); //Töröljük a json adatszerkezet tartalmát, mert már nincs szükségünk rá!
}

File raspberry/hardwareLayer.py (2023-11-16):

7# -*- coding: utf-8 -*-

#Fontos azt megjegyezni, hogy az olvasótól kért muvelet csak a kártya hozzáérintése után fut le!

#Beimprtáljuk a szükséges könyvtárakat
import base64
import os
import json
import serial
import threading
import time
import sys
import RPi.GPIO as GPIO
from mfrc522 import SimpleMFRC522
import requests
from dotenv import load_dotenv
import subprocess

#Betöltjük a .env file-t

load_dotenv()

#internalCardDetected = False #Létrehozunk egy globális változót a belső kártyaérintés érzékelésére

#Ellenőrizzük azt, hogy telepítési módban indul-e az olvasó?
setupMode = False #Ha a telapítési módhoz szükséges argumentumot megkapjuk, akkor ezt átállítjuk True-ra
if len(sys.argv) == 2: #Ha az argumentumok száma 2
    if sys.argv[1] == "setup": #Ha a 2. argumentum értéke setup, akkor... 
        setupMode = True #Átállítjuk a változó értékét True-ra

#Definiáljuk a LED pineket

redPin = 12
greenPin = 13
bluePin = 15

#Beaálítjuk a relé portot tartalmazó globális változót

relay = 11 #Kimeneti pin

#Inicializáljuk a soros kapcsolatot
interface = "/dev/ttyAMA0" #Sorosport neve
connection = serial.Serial(port=interface, baudrate=9600) #Létrehozunk egy sorosportos kapcsolatot
connection.reset_input_buffer() #Töröljük a soros buffert a tiszta indulás érdekében

#Beállítjuk a kártya validálás linkjét
getMethodsUrl = 'https://mlevente.hu/belepteto/api/validation/get-methods'
validateUrl = "https://mlevente.hu/belepteto/api/validation/validate"
logUrl = "https://mlevente.hu/belepteto/log"
setupUrl = "https://mlevente.hu/belepteto/setup"
getCommandUrl = "https://mlevente.hu/belepteto/api/poll/get-command"
logCommandStateUrl = "https://mlevente.hu/belepteto/api/poll/log-command-state"

#Inicializájuk a Buzzer globális változóit 
buzzer = 7 #Kimeneti pin
buzzerTime = (1 / 2400) / 2 #Periódusidő/2

#Inicializáljuk a GPIO-t
GPIO.setmode(GPIO.BOARD) #BOARD pin kiosztás használata, azért, mert az idióta RFID könyvtár is ezt használja
GPIO.setup(buzzer,GPIO.OUT) #Buzzer pin kimenetre állítása
GPIO.setup(relay,GPIO.OUT) #Relé pin kimenetre állítása
GPIO.setup(redPin,GPIO.OUT) #Piros LED pin kimenetre állítása
GPIO.setup(greenPin,GPIO.OUT) #Zöld LED pin kimenetre állítása
GPIO.setup(bluePin,GPIO.OUT) #Kék LED pin kimenetre állítása
GPIO.output(relay, GPIO.HIGH) #Relé alapállapotba állítása

#Inicicializáljuk a webkamerát
filename = "photo.jpg" #Definiáljuk a fájnevet

#Létrehozunk egy globális változót jelenleg futtatott utasítás azonosítására
currentCommandRef = ""

def Authenticate(uid, entry, code, fingerprint, filename): #Az az authnetikációért felelős függvény
    URL = validateUrl
    try:
        print(entry)
        if(entry):
            if(filename != ""):
                file = open(filename, 'rb') #Megnyitjuk a képet
                print("Kép megnyitva")
                b64 = base64.b64encode(file.read()) #Átalakítjuk a képet BASE64 formátumúvá
                print("Kép átalakítva")
                data = {'access_token': os.getenv('ACCESS_TOKEN'), 'uid' : uid, 'code' : code, 'fingerprint' : fingerprint, 'entry': entry, 'picture' : b64}
                print(data)
                r = requests.post(URL, data = data)
            else:
                data = {'access_token': os.getenv('ACCESS_TOKEN'), 'uid' : uid, 'code' : code, 'fingerprint' : fingerprint, 'entry': entry}
                print(data)
                r = requests.post(URL, json = data)
        else:
             data = {'access_token': os.getenv('ACCESS_TOKEN'), 'uid' : uid, 'code' : code, 'fingerprint' : fingerprint, 'entry': entry}
             print(data)
             r = requests.post(URL, json = data)
        j = json.loads(json.dumps(r.json()))
        print(j)
        return j.get("success")
    except:
        print("kivétel történt!")
        return False

def SetLedColor(color):
    if color == "red": #Piros szín esetén
        GPIO.output(redPin, GPIO.HIGH)
        GPIO.output(greenPin, GPIO.LOW)
        GPIO.output(bluePin, GPIO.LOW)
    if color == "green": #Zöld szín esetén
        GPIO.output(redPin, GPIO.LOW)
        GPIO.output(greenPin, GPIO.HIGH)
        GPIO.output(bluePin, GPIO.LOW)
    if color == "blue": #Kék szín esetén
        GPIO.output(redPin, GPIO.LOW)
        GPIO.output(greenPin, GPIO.LOW)
        GPIO.output(bluePin, GPIO.HIGH)
    if color == "none": #Kikapcsolt állapot esetén
        GPIO.output(redPin, GPIO.LOW)
        GPIO.output(greenPin, GPIO.LOW)
        GPIO.output(bluePin, GPIO.LOW)

def TriggerRelay(): #Relét kapcsoló metódus
    GPIO.output(relay, GPIO.LOW)
    time.sleep(0.1)
    GPIO.output(relay, GPIO.HIGH)

def TakePhoto(filename): #A fénykép készítésért felelős metódus
        webcamProcess = subprocess.run(["fswebcam", "--deinterlace", "-q", "-r", "640x480", filename]) #A returncode=0 azért kell, hogy kivételt emeljen a Python amennyiben valami hiba történne a kép készítesekkor
        if(webcamProcess.returncode == 0): #Ha a fswebcam futás során nullás kóddal lép ki!
            return True
        else:
            return False

def GetMethods(uid): #UID alapján megkapjuk az adott felhasználó hitelesítési módjait
    URL = getMethodsUrl
    print(URL)
    data = {'access_token': os.getenv('ACCESS_TOKEN'), 'uid' : uid}
    r = requests.post(URL, json = data)
    print("GetMethods(): " + str(r.status_code))
    #print the response text (the content of the requested file):
    print(r.status_code)
    if r.status_code == 200:
        try:
            j = json.loads(json.dumps(r.json()))
            return j
        except:
            return False
    else:
        return False

def GetCommand(): #UID alapján megkapjuk az adott felhasználó hitelesítési módjait
    URL = getCommandUrl
    print(URL)
    data = {'access_token': os.getenv('ACCESS_TOKEN')}
    r = requests.post(URL, json = data)
    print("GetCommand(): " + str(r.status_code))
    #print the response text (the content of the requested file):
    print(r.status_code)
    if r.status_code == 200:
        try:
            j = json.loads(json.dumps(r.json()))
            return j
        except:
            return False
    else:
        return False

def LogCommandState(reference_token, state, message): #A parancsok lefutásának sikereségét a szerver felé továbbító metódus
    URL = logCommandStateUrl
    print(URL)
    data = {'access_token': os.getenv('ACCESS_TOKEN'), 'reference_token': reference_token, 'state': state, 'message': message}
    r = requests.post(URL, json = data)
    print("LogCommandState(): " + str(r.status_code))
    #print the response text (the content of the requested file):
    print(r.status_code)
    if r.status_code == 200:
        return True #200-as kód esetén igaz értéket adjunk vissza
    else:
        return False


def ShortBeep(): #Rövid csippanást lejátszó metódus
    for i in range(600):
    	GPIO.output(buzzer, GPIO.LOW)
    	time.sleep(buzzerTime)
    	GPIO.output(buzzer, GPIO.HIGH)
    	time.sleep(buzzerTime)
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

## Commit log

2023-04-14 Added Raspberry pi program
2023-04-29 Fix adduser button
2023-05-03 Arduino code added to the project
2023-05-04 Added new files to the project
    [belepteto.fzz, belepteto_rpi.fzz]
2023-05-05 Added /current page to the project
2023-05-06 Profile picture added to /current /users
2023-05-31 Update back button on user edit view
2023-05-31 Fix /current bug
2023-06-10 Less blinking in /current
2023-08-07 DarkMode Button added
2023-08-09 Raspberry pi pcb and schematics added
    [belepteto.fzz, belepteto_rpi.fzz]
2023-08-30 Update RPi PCB
2023-09-06 Fingerprint reading implementation
2023-09-14 /current improved, test
2023-09-19 /current polling done
2023-09-24 Change keyboard controll functions + json structure in Arduino code
2023-10-02 Fingerprint record option added to Dashboard
2023-10-05 Fingerprint reading implented in hardwareLayer
2023-10-05 Some bug fixed, but it still not working
    [hardwareLayer.py]
2023-10-09 ValidationController code/fingerprint check added
2023-10-10 Fix system side logs table on mobile devices
2023-10-10 Refactor Arduino code
2023-10-12 Fingerprrint reading works
2023-10-12 Error handling added to FP enroll process
    [hardwareLayer.py]
2023-10-27 Update Arduino code
2023-11-01 Arduino/readme moved to readme
2023-11-07 Update README.md
    Add Arduino <-> Raspberry Pi cable pinout
2023-11-10 Add warn to fingerprint record overwrite
2023-11-14 Fingerprint ID input check added
2023-11-28 Update PCBs
2023-11-28 Update fingerprint enroll diagram
2023-11-29 Update fingerprint search process diagram
